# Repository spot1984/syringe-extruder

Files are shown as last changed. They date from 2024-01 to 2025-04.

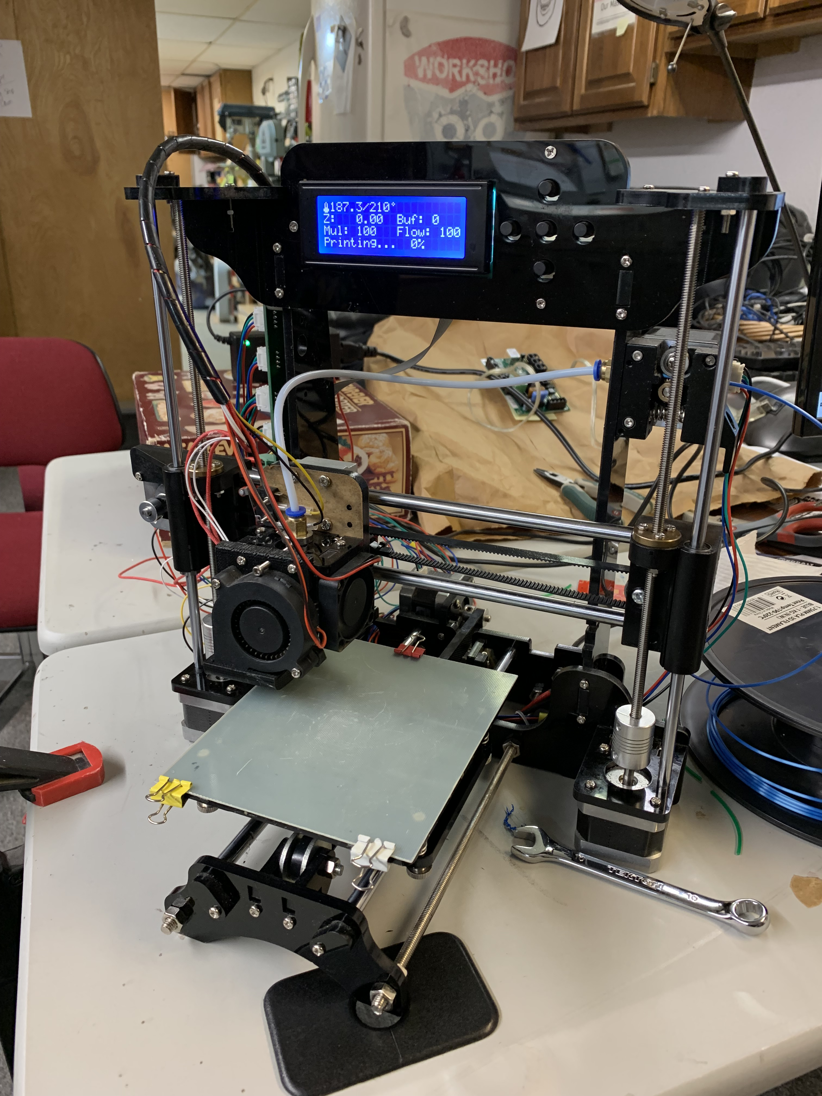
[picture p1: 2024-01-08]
IMG_2513.JPG

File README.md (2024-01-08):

# syringe-extruder
*by D. Scott Williamson* (c) 2024 All rights reserved

This project is released under the MIT License

# project

This project is intended to convert a Tronxy 3D printer into a syringe extruder capable of extruding clay, dough, chocolate, frosting, or similar materials from a plastic syringe.  The design is intended to re-use the existing motion platform and extruder stepper motor in a new configuration with mostly 3D printed parts. The CAD is done in OpenSCAD.

The initial design will use a plastic 60cc syringe that may be increased to 150cc if successful.

## bom
3D printed parts:
* Carriage mount for motor and syringe
* Plunger holder

Non 3D printed parts:
* 5mm to 1/4" shaft coupler
* 300mm 1/4"-20 threaded rod
* 2x 1/4"-20 nuts

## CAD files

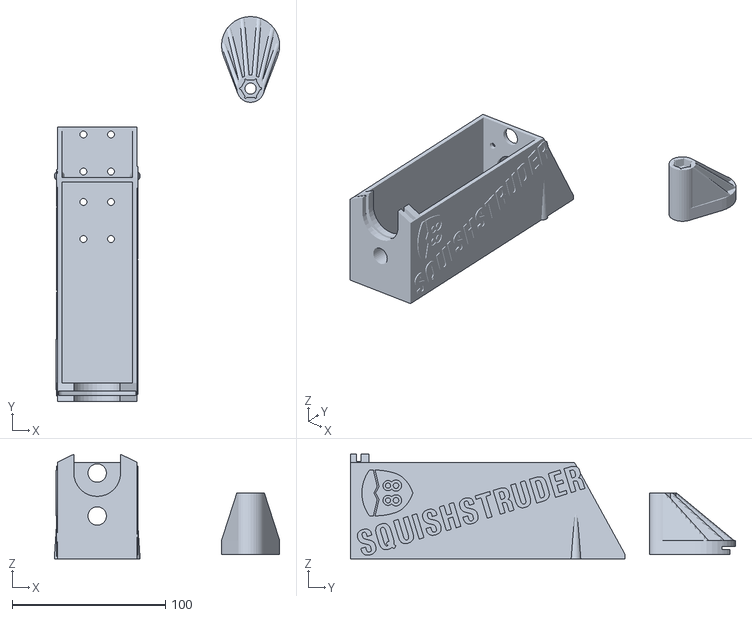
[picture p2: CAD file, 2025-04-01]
Syringe extruder.stl
147.0 x 251.0 x 68.4

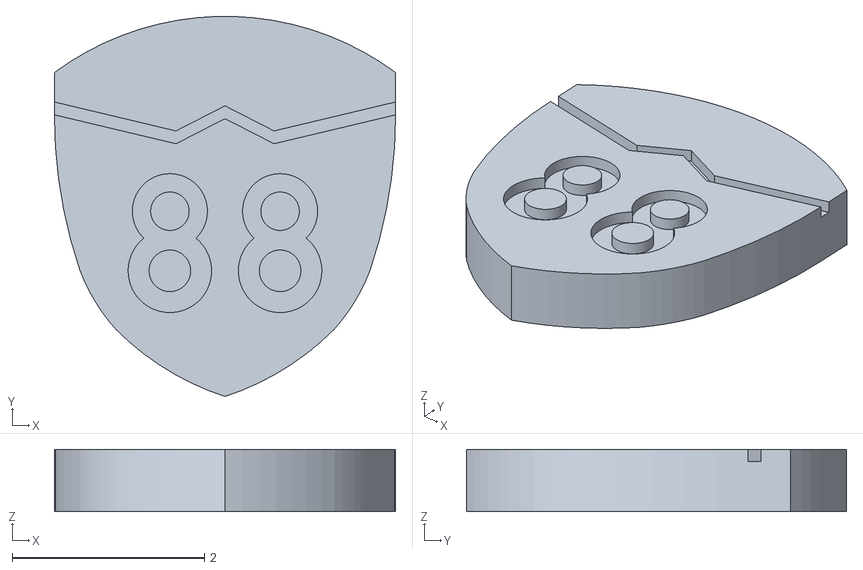
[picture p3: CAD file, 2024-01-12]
W88_logo.stl
3.55 x 3.95 x 0.65

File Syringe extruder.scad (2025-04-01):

/*
    Squishstruder - Syringe Extruder for Tronxy
    by D. Scott Williamson 1/4/2024 
    
    (c) copyright 2024 All rights reserved.

    todo
        [] Rename git repo
        [-] Rebuild in FreeCAD - decided it was too much effort
        [-] Parametric for different syringes
        [-] Customizer


    version history
    v2.1
        [] Redesign acutator to hold plunger for retraction

    v2.0
        [x] Thicken belt screw walls
        [x] Raise motor and syringe mount for more clearance
            [x] Bring motor and syringe forward to clear mounting screw heads
        [x] syringe flange holder for retraction and to prevent rotation
            [x] Flange holder
    v1.1
        [x] Mounting screw holes larger (3.3 -> 4.5)
        [x] Vertical screw spacing on mount needs to be wider (24.185)
    v1.0 Printed on Voron in blue PLA 4 walls .3mm layers
        [x] Model syringe
        [x] Drive
            [x] Stepper motor
            [x] Shaft coupler
            [x] Threaded rod
        [x] Design mounting plate frame
            [x] Mount to printer
            [x] Stepper motor mount
            [x] Syringe mount
            [x] Workshop 88 logo
            [x] Version number
            [x] Rename Squishstruder
            [x] Precise mounting hole locations
        [x] Design actuator plunger holder
            [x] Plunger interface (Actuator cannot lift plunger for retraction)
            [x] Dual nut capture 
        [-] Redesign actuator to print on its back and the plunger top fits in a slot for retraction
        [x] Need screw holes in back for screws to hold belts
        [x] Thickened area around belt mounting screws
        [-] gusset for belt screws that does not interfere with mounting screws
*/


ver="v2.1";    // Version

// layer height
nozzled=0.4;
lh=.35;     //[.1:.05:1]

syringe_body_wall_thickness=1.5;
syringe_body_diameter=29.5;         // [2:80]
syringe_body_length=134;            // [2:200]
syringe_body_diameter1=11.22;       // [2:80]
syringe_body_length1=5;
syringe_body_diameter2=6.8;         // [2:80]
syringe_body_length2=43;

syringe_body_flange_width=50;
syringe_body_flange_diameter=33.2;
syringe_body_flange_length=18;

syringe_body_flange_radius=4;
syringe_body_flange_thickness=2.6;

syringe_plunger_head_diameter=31;   // [2:80]
syringe_plunger_thickness=2;   // [1:8]
syringe_plunger_length1=130;         // [10:200]
syringe_plunger_length2=12;         // [10:200]
syringe_plunger_length=142;         // [10:200]
syringe_plunger_throw=127.5-12;     // [10:200]
syringe_plunger_wall_width=24.6;
syringe_plunger_wall_width2=16.8;

syringe_plunger_tip_thickness=5;


clearance=nozzled*.5;
nema17r1=22/2+clearance*2;
nema17screwoffset=31/2;
nema17screwholer=(3/2)+clearance;
nema17motorw=42.3;
nema17cornerr=4;
nema17offset=44/2;

$fn=32;

mount_thickness=3;
mount_height=180;
mount_width=52; //44;
mount_depth=60;
mount_hole_diameter=12;
mount_syringe_offset=50;


actuator_thickness=mount_thickness;
actuator_width=44;
actuator_depth=60;
actuator_rod_diameter=18;
actuator_plunger_id=syringe_plunger_head_diameter+1;
actuator_plunger_od=actuator_plunger_id+actuator_thickness*2;
actuator_height=40;

quarter20nut_flatd=11;
quarter20nut_h=5.6;
quarter20nut_id=.25*25.4;

xbearingspacing=44;
xbearingy1=20;
xbearingy2=xbearingy1+xbearingspacing;
mount_screw_spacing_x=18;
mount_screw_spacing_y=24.185;   // v1.0 25;
mount_belt_screw_spacing=mount_width-mount_thickness; //42;

// x bearing ends look like i3 58mm tall, bearings xbearingspacingmm apart
///////////////////////////////////////////////////////////////////////////////
// Variables after here will not appear in the cutomizer
module hide_from_customizer() {} 

plunge=-30;//-syringe_plunger_throw*(sin($t*360)/2+.5);

raisefloor=36;
screwclearance=3;

///////////////////////////////////////////////////////////////////////////////
// Preview
// Guides for develoment
if ($preview){
    ty(screwclearance) tz(raisefloor) {
        
        t([0,mount_syringe_offset,142])rx(180)rz(00) {
            tz(plunge-actuator_thickness+.65) rz(45) plunger();
            syringe();
        }
        ty(nema17offset) {
            nema17steppermotor(pinion=false);
            color([.4,.4,.4]) tz(5) rz(plunge*20/25.4*360) coupler();
            color([.6,.6,.6]) tz(15) rz(plunge*20/25.4*360) cylinder(d=.25*25.4,h=300);    // Threaded rod
            color([.8,.8,.8]) tz(156-plunge-actuator_thickness-.1) nut(flatd=quarter20nut_flatd,h=quarter20nut_h,id=quarter20nut_id);
            color([.8,.8,.8]) tz(156-plunge-actuator_thickness+actuator_height-quarter20nut_h+.1) nut(flatd=quarter20nut_flatd,h=quarter20nut_h,id=quarter20nut_id);
        }

        color([.1,.3,.7]) tz(156-plunge-actuator_thickness) actuator();
    }

    //color([.1,.8,.8]) retainer();
    color([.1,.2,.8]) mount();
    
    // bearing rails
    color([.8,.8,.8]) for(i=[0,xbearingspacing]) t([-100,-4-mount_thickness-4,xbearingy1+i]) ry(90) cylinder(d=8,h=200);

    
    //t([0,0,10])nema17mountingplate();
    //#t([0,0,20])nema17holes();
    //tz(3) ty(100)nut(flatd=quarter20nut_flatd,h=quarter20nut_h,id=quarter20nut_id);
    //#ty(100)nuthole(flatd=quarter20nut_flatd+.5,h=quarter20nut_h+.4);
}
else{
    tx(-50) rx(90) mount();
    tx(50) actuator();
}


///////////////////////////////////////////////////////////////////////////
// modules

// 10mm wide W88 logo
module w88logo()
{
	s=2.8;
	scale([s,s,2]) translate([-8.1,-2.1,-2.6 /*+.125*/])
	import("w88_logo.stl");
}

// Actuator rides on threaded rod and moves the syringe plunger
module actuator()
{
    difference() {
        union() {
            hull() {
            ty(nema17offset) cylinder(d=actuator_rod_diameter,h=actuator_thickness*3);
            ty(mount_syringe_offset) cylinder(d=actuator_plunger_od,h=actuator_thickness*3);
            }
            
            ty(nema17offset) cylinder(d=actuator_rod_diameter,h=actuator_height);
            
            for(a=[-90:36:90]) {
                s=sin(a);
                c=cos(a);
                hull() {
                    t([s*(actuator_plunger_od/2-actuator_thickness/2),mount_syringe_offset+c*(actuator_plunger_od/2-actuator_thickness/2),0]) cylinder(d=actuator_thickness,h=actuator_thickness*3);
                    t([s*(actuator_rod_diameter/2-actuator_thickness/2),nema17offset+c*(actuator_rod_diameter/2-actuator_thickness/2),0]) cylinder(d=actuator_thickness,h=actuator_height);
                }
            }
        }
        
        // recess for top of syringe
        hull() for(y=[0,30])t([0,mount_syringe_offset+y,actuator_thickness])
            cylinder(d=syringe_plunger_head_diameter+1,h=syringe_plunger_thickness+.25);
        
        // slot for neck of syringe
        hull() for(y=[0,30])t([0,mount_syringe_offset+y,-.1]) 
            cylinder(d=22,h=syringe_plunger_thickness*2+.5+.2);
        
        ty(nema17offset) {
            // bottom nut hole
            tz(-.1) nuthole(flatd=quarter20nut_flatd+.5,h=quarter20nut_h+.4);
            // top nut hole
            tz(-.1) cylinder(d=.25*25.1+1, h=actuator_height+1);
            tz(actuator_height-quarter20nut_h) nuthole(flatd=quarter20nut_flatd+.5,h=quarter20nut_h+.4);
        }
    }
}

module plunger(){
    tz(-syringe_plunger_thickness-syringe_plunger_length2) {
        color([.91,.91,1,.5]) {
            tz(0) cylinder(d=syringe_plunger_head_diameter,h=syringe_plunger_thickness);   
            for(a=[0,90])rz(a) hull() {
                cube([syringe_plunger_wall_width2,syringe_plunger_thickness,.01],center=true);
                tz(syringe_plunger_length2) cube([syringe_plunger_wall_width,syringe_plunger_thickness,.01],center=true);
                tz(syringe_plunger_length) cube([syringe_plunger_wall_width,syringe_plunger_thickness,.01],center=true);
            }
        }
        color([.1,.1,.1]) tz(syringe_plunger_length) cylinder(d=syringe_body_diameter-2*syringe_body_wall_thickness,h=syringe_plunger_tip_thickness);   
    }
}

// Mount to the body of the printer
module mount()
{
    difference() {
        union() {
            // back
            t([-mount_width/2,-mount_thickness,3]) cube([mount_width,mount_thickness,mount_height-3]);
            // motor mount
            t([-mount_width/2,-mount_thickness,raisefloor]) cube([mount_width,mount_depth+mount_thickness,mount_thickness]);
            
            // gussets
            for (x=[-1,1]) tx(x*(mount_width/2-mount_thickness/2)-mount_thickness/2) hull(){
                tz(3)cube([mount_thickness,.01,mount_height-3]);    // the 3 is for connector clearance
                tz(syringe_body_length+raisefloor+12-1)cube([mount_thickness,mount_depth,1]);  // top to make a box
                t([0,-mount_thickness,raisefloor]) cube([mount_thickness,mount_depth+mount_thickness,mount_thickness]);
            }
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

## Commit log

2024-01-08 Added OpenSCAD files v01 and v02
    [Syringe extruder v01.scad, Syringe extruder v02.scad]
2024-01-08 Added picture of Tronxy printer
2024-01-08 Add initial mount
    [Syringe extruder v02.scad]
2024-01-08 Replaced manually versioned file with a single OpenSCAD source file.
    [Syringe extruder v01.scad, Syringe extruder.scad]
2024-01-08 Add actuator, nuts, and nut holes. Still a work in progress.
    [Syringe extruder.scad]
2024-01-08 Better stronger actuator but it still cannot retract
    [Syringe extruder.scad]
2024-01-08 Added workshop 88 logo, squishstruder name, and version number.
    [Syringe extruder.scad]
2024-01-12 Add Workshop 88 logo stl
    [W88_logo.stl]
2024-01-12 Actual mounting screw locations and holes for screws to hold the X belt
    [Syringe extruder.scad]
2024-01-18 Working on improved actuator.
    [Syringe extruder.scad]
2024-01-20 Put off retraction, fixed text and logo, added strength aroung belt holding screws.
    [Syringe extruder.scad]
2024-01-30 Updated comments
    [Syringe extruder.scad]
2024-01-30 Added .stl
    [Syringe extruder.stl]
2025-03-30 updated todo, false start on retainer for retraction
    [Syringe extruder.scad]
2025-03-31 v1.1 mounting holes larger, fixed spacing
    [Syringe extruder.scad, Syringe extruder.stl]
2025-03-31 v2.0 Raised floor, moved motor forward for screw clearance, made wider and taller, added retaining clip for syringe
    [Syringe extruder.scad, Syringe extruder.stl]
2025-04-01 v2.1 added plunger retainer to the top for retraction (printed success)
    [Syringe extruder.scad, Syringe extruder.stl]
